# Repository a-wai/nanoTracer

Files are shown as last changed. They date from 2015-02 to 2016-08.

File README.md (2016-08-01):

# nanoTracer
nanoTracer is a basic curve tracer for vacuum tubes. It uses an Arduino for its brain and a simple analog circuit provides measurements command and amplification.

## Dependencies
In order to build this software, you need the following packages :

- GNU make
- avr-gcc
- avr-libc
- avr-binutils
- avrdude

These can be obtained by typing the following command on Debian or Ubuntu systems :

`sudo apt-get install avr-gcc avr-libc avr-binutils avrdude`

## Building nanoTracer
Simply `cd` into the `nanoTracer` directory and use the `make` command.

## Uploading nanoTracer to your device
nanoTracer is compatible with Arduino boards. Once the software has been built, simply type `make upload` to write the software to your device.

When using the AVR Dragon programmer, you need to modify a few variables in the Makefile :

- `PROGRAMMER	= dragon_isp`
- `PROG_PORT	= usb`

## Usage
The Arduino needs to be connected to a computer through USB. The use of a serial terminal, such as `minicom` or `Putty` is required, with a baudrate of 500kbps.

With minicom, use the command `minicom -D /dev/ttyACM0 -b 500000 -o -w`, and make sure to disable software and hardware flow control.

Once the Arduino is ready, it should ouput the string `Starting...`. You can then select the tube type you want to measure by typing its number in the serial terminal window :

- `1` for an ECC81
- `2` for an ECC82
- `3` for an ECC83
- `8` for an ECC88
- `9` for an ECC99

The measure is started by typing `#` in the serial terminal or pressing the hardware button connected to pin D2. The Arduino then outputs a list of measures of the form :

```
Vg = 20
57,1
76,1
92,2
108,5
...
```

Each `Vg = ` line indicates the grid voltage used for this measurement. It is expressed in tenths of volts, for instance, `Vg = 20` means the grid voltage is -2V.

The following lines are the measurements in CSV format, the first value being the anode voltage in V, and the second value being the anode current in tenths of milliamperes. Thus, the line `92,2` means the tube was drawing 0.2mA when the anode voltage was 92V (and the grid voltage -2V). You can then copy/paste these lines in your favorite spreadsheet to exploit the measurements (see the example LibreOffice file in the `spreadsheet/` directory).

## Harware
nanoTracer is a DIY project. You will find all the information needed to build your own tracer under the `kicad/` directory.

## License
Source code for the software is distributed under the GNU GPL v3 license. Please see the COPYING.software file or [the GNU website](http://www.gnu.org/licenses/#GPL) for details.

Hardware design files are distributed under the CERN Open Hardware Licence v1.2. Please see the COPYING.hardware file or [the Open Hardware Repository website](http://www.ohwr.org/licenses/cern-ohl/v1.2) for details.

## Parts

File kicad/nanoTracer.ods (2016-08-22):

Designator | Package | Qty | Value | RS Reference
 | 2.54mm Jumpers | 3 |  | 674-2397
P7 (optional) | Pin Header Straight 1x2 | 1 |  | 251-8086
SHIELD1,JP1,JP2,P6 | Pin Header Straight 1x40 | 1 |  | 156-049
D1,D3 | Rectifier Bridge WOG | 2 | B80C1500 | 700-5396
D2 | Rectifier Bridge WOG | 1 | B380C1500 | 629-6011
P3 | Bornier 3 | 1 |  | 897-0705
P1,P2,P4,P5 | Bornier 2 | 4 |  | 896-6696
C4,C5 | C_Rect_L18_W6_H12_P15 | 2 | 100n | 869-7469
C13,C2,C3,C10,C11,C14,C15 | C_Rect_L7_W2_P5 | 7 | 100n | 334-221
C1 | C_Radial_D10_L16_P5 | 1 | 1000µ | 862-3099
C6 | C_Radial_D7.5_L11.2_P2.5 | 1 | 220µ | 228-6919
C7 | C_Radial_D6.3_L11.2_P2.5 | 1 | 100µ | 228-6767
R12 | Resistor | 1 | 1R | 150-565
R16 | Resistor | 1 | 120R | 148-281
R5,R13 | Resistor | 2 | 1k | 148-506
R11 | Resistor | 1 | 2.2k | 148-584
R15 | Resistor | 1 | 2.4k | 148-590
R4 | Resistor | 1 | 5.1k | 148-253
R6,R7,R14 | Resistor | 3 | 10k | 148-736
R3 | Resistor | 1 | 15k | 148-770
R2 | Resistor | 1 | 82k | 148-950
R8,R9 | Resistor | 2 | 100k | 148-972
R10 | Resistor | 1 | 220k | 149-060
U1,U2,U3,U5 | DIP-8 Socket | 4 |  | 674-2479
U1 | DIP-8 | 1 | TL072 | 304-239
U2 | DIP-8 | 1 | TL071 | 304-245
U3 | DIP-8 | 1 | MCP4921-E/P | 738-6027
U4 | TO-220 | 1 | LM337T | 464-104
U5 | DIP-8 | 1 | MCP3202 | 403-115

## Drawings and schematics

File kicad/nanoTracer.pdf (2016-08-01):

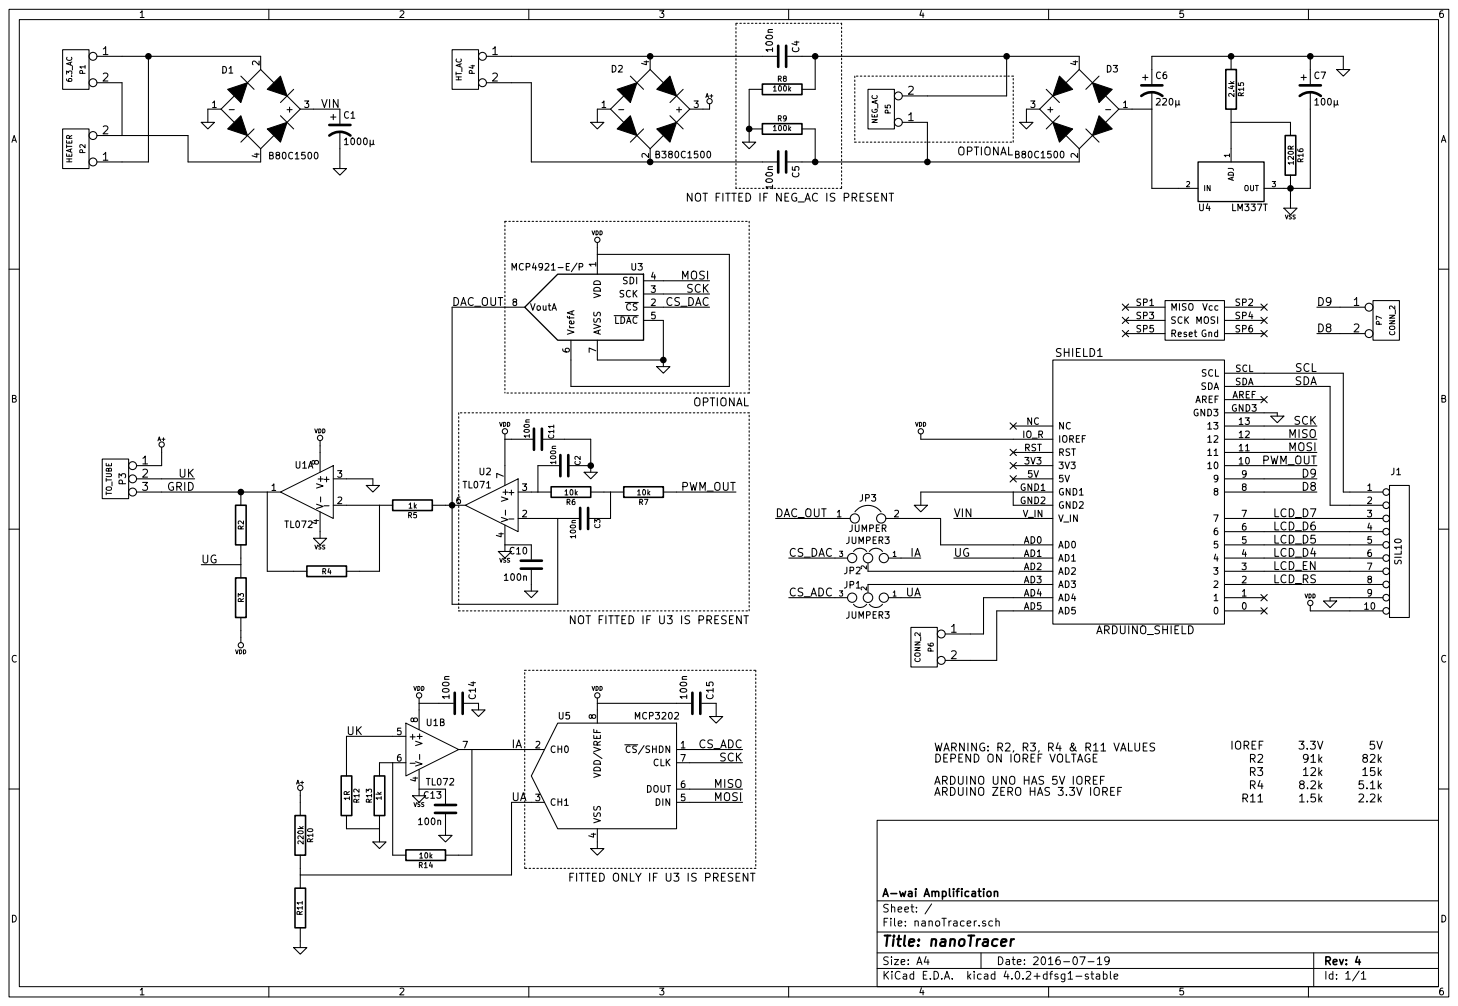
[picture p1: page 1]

100k NOT FITTED IF U3 IS PRESENT

NOT FITTED IF NEG_AC IS PRESENT

FITTED ONLY IF U3 IS PRESENT R2

DEPEND ON IOREF VOLTAGE
ARDUINO UNO HAS 5V IOREF

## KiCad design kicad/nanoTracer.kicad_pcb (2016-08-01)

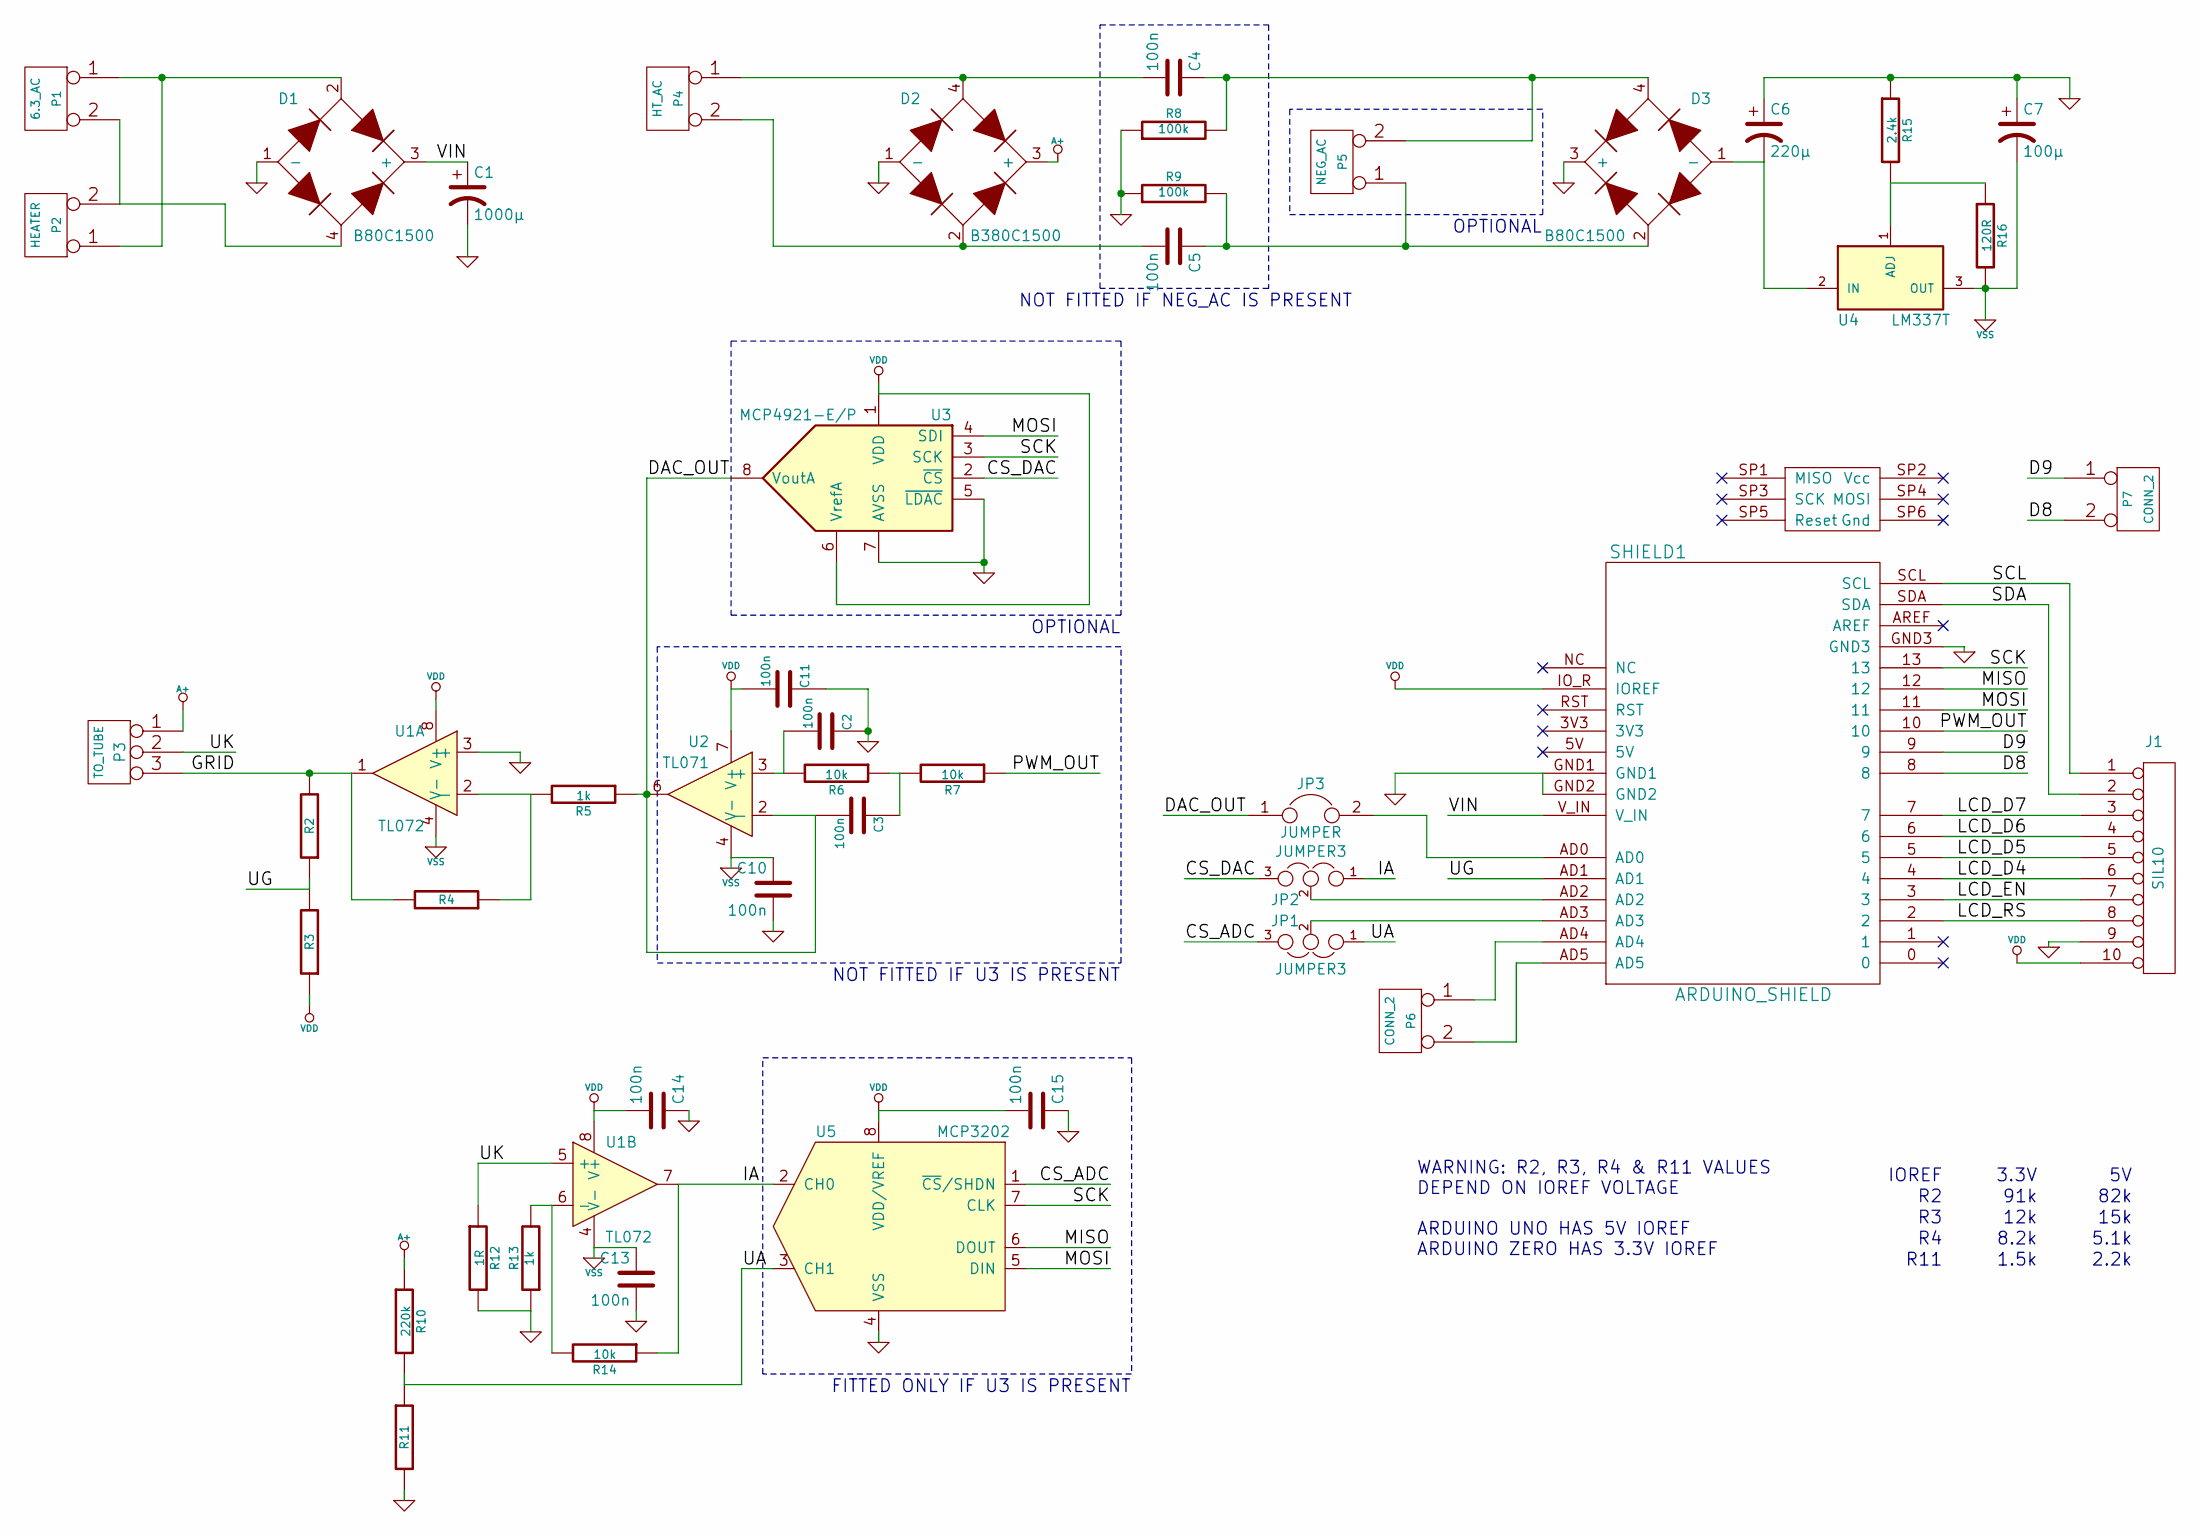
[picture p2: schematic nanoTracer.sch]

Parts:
C1: 1000µ; C_Radial_D10_L16_P5
C2, C3, C10, C11, C13, C14, C15: 100n; C_Rect_L7_W2_P5
C4, C5: 100n; C_Rect_L18_W6_H12_P15
C6: 220µ; C_Radial_D7.5_L11.2_P2.5
C7: 100µ; C_Radial_D6.3_L11.2_P2.5
D1, D3: B80C1500; bridge_wob
D2: B380C1500; bridge_wob
J1: SIL10; Pin_Header_Straight_1x10
JP1, JP2: JUMPER3; Pin_Header_Straight_1x03
JP3: JUMPER; SJ_OPEN
P1: 6.3_AC; bornier2
P2: HEATER; bornier2
P3: TO_TUBE; bornier3
P4: HT_AC; bornier2
P5: NEG_AC; bornier2
P6, P7: CONN_2; Pin_Header_Straight_1x02
R2: R2; Resistor_Horizontal_RM10mm
R3: R3; Resistor_Horizontal_RM10mm
R4: R4; Resistor_Horizontal_RM10mm
R5, R13: 1k; Resistor_Horizontal_RM10mm
R6, R7, R14: 10k; Resistor_Horizontal_RM10mm
R8, R9: 100k; Resistor_Horizontal_RM10mm
R10: 220k; Resistor_Horizontal_RM10mm
R11: R11; Resistor_Horizontal_RM10mm
R12: 1R; Resistor_Horizontal_RM10mm
R15: 2.4k; Resistor_Horizontal_RM10mm
R16: 120R; Resistor_Horizontal_RM10mm
SHIELD1: ARDUINO_SHIELD
U1: TL072; DIP-8_W7.62mm_LongPads
U2: TL071; DIP-8_W7.62mm_LongPads
U3: MCP4921-E/P; DIP-8_W7.62mm_LongPads
U4: LM337T; TO-220_Neutral123_Vertical
U5: MCP3202; DIP-8_W7.62mm_LongPads

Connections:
/CS_ADC: JP1.3, U5.1 (~CS~/SHDN)
/CS_DAC: JP2.3, U3.2 (~CS~)
/D8: P7.2, SHIELD1.8
/D9: P7.1, SHIELD1.9
/DAC_OUT: C3.2, JP3.1, R5.1, U2.2 (-), U2.6, U3.8 (VoutA)
/GRID: P3.3, R2.2, R4.2, U1.1
/IA: JP2.1, R14.1, U1.7, U5.2 (CH0)
/LCD_D4: J1.6, SHIELD1.4
/LCD_D5: J1.5, SHIELD1.5
/LCD_D6: J1.4, SHIELD1.6
/LCD_D7: J1.3, SHIELD1.7
/LCD_EN: J1.7, SHIELD1.3
/LCD_RS: J1.8, SHIELD1.2
/MISO: SHIELD1.12, U5.6 (DOUT)
/MOSI: SHIELD1.11, U3.4 (SDI), U5.5 (DIN)
/PWM_OUT: R7.1, SHIELD1.10
/SCK: SHIELD1.13, U3.3 (SCK), U5.7 (CLK)
/SCL: J1.1, SHIELD1.SCL
/SDA: J1.2, SHIELD1.SDA
/UA: JP1.1, R10.2, R11.1, U5.3 (CH1)
/UG: R2.1, R3.2, SHIELD1.AD1
/UK: P3.2, R12.1, U1.5 (+)
/VIN: C1.1, D1.3 (+), SHIELD1.V_IN
A+: D2.3 (+), P3.1, R10.1
GND: C1.2, C2.1, C6.1, C7.1, C10.2, C11.1, C13.2, C14.1, C15.1, D1.1 (-), D2.1 (-), D3.3 (+), J1.9, R8.1, R9.1, R11.2, R12.2, R13.1, R15.1, SHIELD1.GND1, SHIELD1.GND2, SHIELD1.GND3, U1.3 (+), U3.5 (~LDAC~), U3.7 (AVSS), U5.4 (VSS)
unnamed: C2.2, R6.2, U2.3 (+)
unnamed: C3.1, R6.1, R7.2
unnamed: C4.1, D3.4, P5.2 (PM), R8.2
unnamed: C4.2, D2.4, P4.1
unnamed: C5.1, D3.2, P5.1, R9.2
unnamed: C5.2, D2.2, P4.2 (PM)
unnamed: C6.2, D3.1 (-), U4.2 (IN)
unnamed: D1.2, P1.1, P2.1
unnamed: D1.4, P1.2 (PM), P2.2 (PM)
unnamed: JP1.2, SHIELD1.AD3
unnamed: JP2.2, SHIELD1.AD2
unnamed: JP3.2, SHIELD1.AD0
unnamed: P6.1, SHIELD1.AD4
unnamed: P6.2, SHIELD1.AD5
unnamed: R4.1, R5.2, U1.2 (-)
unnamed: R13.2, R14.2, U1.6 (-)
unnamed: R15.2, R16.1, U4.1 (ADJ)
VDD: C11.2, C14.2, C15.2, J1.10, R3.1, SHIELD1.IO_R (IOREF), U1.8 (V+), U2.7 (V+), U3.1 (VDD), U3.6 (VrefA), U5.8 (VDD/VREF)
VSS: C7.2, C10.1, C13.1, R16.2, U1.4 (V-), U2.4 (V-), U4.3 (OUT)

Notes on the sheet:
NOT FITTED IF U3 IS PRESENT
NOT FITTED IF NEG_AC IS PRESENT
FITTED ONLY IF U3 IS PRESENT
OPTIONAL
IOREF
R11
3.3V
82k
15k
5.1k
2.2k
1.5k
8.2k
12k
91k
WARNING: R2, R3, R4 & R11 VALUES DEPEND ON IOREF VOLTAGE ARDUINO UNO HAS 5V IOREF ARDUINO ZERO HAS 3.3V IOREF

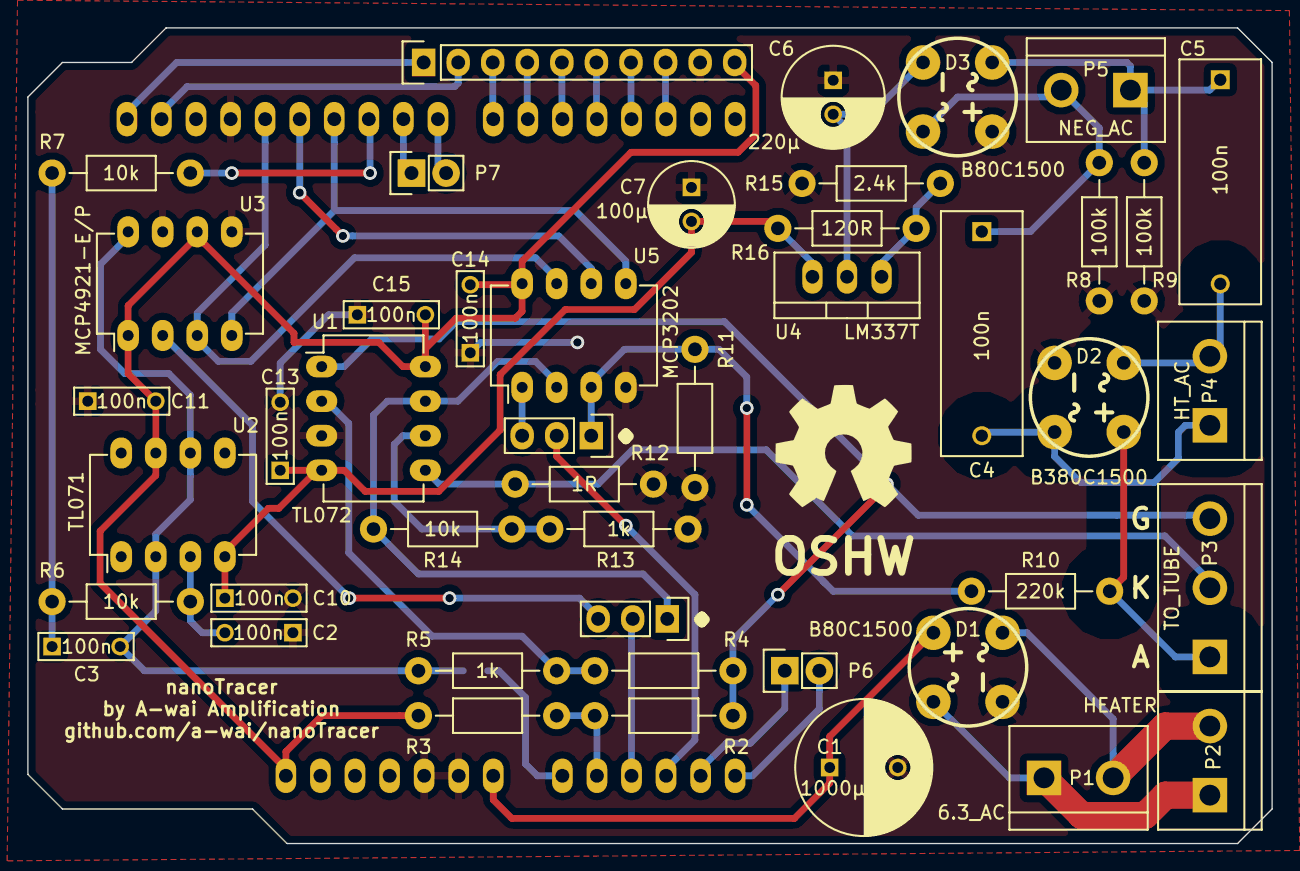
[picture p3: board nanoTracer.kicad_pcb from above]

Board: 2 copper layers, 91.4 x 59.9 mm, 48 parts (0 on the bottom side), 44 nets.

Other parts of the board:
LOGO_OSHW_silkscreen_10mm: val**; LOGO_OSHW_silkscreen_10mm

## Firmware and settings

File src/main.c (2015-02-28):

/*
 * Copyright (C) 2015 Arnaud Ferraris.
 *
 * This file is part of nanoTracer.
 *
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
 */

#include "main.h"
#include "tracer.h"

static program_mode_t mode = MODE_NONE;

static void mcuInit(void)
{
  // Enable sleep mode in idle mode
  SMCR = _BV(SE);

  // Disable ADC power reduction
  BITCLR(PRR, PRADC);
}

static void ioInit(void)
{
  // Configure pin D2 as input
  BITCLR(BTN_PORT, BTN_PIN);
  BITCLR(BTN_DDR, BTN_PIN);

  // Enable external interrupt on falling edge for pin D2
  EICRA = _BV(ISC00) | _BV(ISC01);
  EIMSK = _BV(INT0);
}

static void pwmInit(void)
{
  // Configure pin D6 as output
  BITSET(PORT_DIG1, PIN_D6);
  BITSET(DDR_DIG1, PIN_D6);

  // Configure TIMER0 for fast PWM
  TCCR0A = _BV(COM0A1) | _BV(WGM01) | _BV(WGM00);
  TCCR0B = _BV(CS00);
  TIMSK0 = 0;
  OCR0A = 200;
}

int main(void)
{
  char cmd;
  program_mode_t willDo = MODE_NONE;

  wdt_disable();

  cli();

  mcuInit();

  ioInit();
  pwmInit();
  serialInit(500000);
  adcInit(PIN_VOLTAGE);

  sei();

  serialDebug("Starting...\r\n");

  for (;;)
  {
    if (willDo)
    {
      mode = willDo;
      willDo = MODE_NONE;
    }
    else
    {
      asm volatile ("sleep\n\t");
    }

    switch (mode)
    {
      case MODE_START_ACQUISITION:
        tracerStartAcquisition();
        break;
      case MODE_CONVERSION_DONE:
        tracerProcessAdc();
        break;
      case MODE_SERIAL_RECEIVED:
        cmd = serialReceive();
        switch (cmd)
        {
          case '#':
            willDo = MODE_START_ACQUISITION;
            break;
          default:
            tracerSelectTube(cmd);
            break;
        }
        break;
      case MODE_SERIAL_SENT:
        serialWrite();
        break;
      default:
        break;
    }

    mode = MODE_NONE;
  }

  return 0;
}

ISR(INT0_vect)
{
  mode = MODE_START_ACQUISITION;
}

ISR(ADC_vect)
{
  mode = MODE_CONVERSION_DONE;
}

ISR(USART_RX_vect)
{
  mode = MODE_SERIAL_RECEIVED;
}

ISR(USART_TX_vect)
{
  mode = MODE_SERIAL_SENT;
}

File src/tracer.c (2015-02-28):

/*
 * Copyright (C) 2015 Arnaud Ferraris.
 *
 * This file is part of nanoTracer.
 *
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
 */

#include "drivers/adc.h"

#include "tracer.h"

#define   MAX_GRID_VOLTAGE  (10 * MAX_NEGATIVE_VOLTAGE)

uint16_t values[64];

static uint8_t  startAcquisition = 0;
static uint16_t oldValue         = 0;
static uint8_t  measureCount     = 0;
static uint8_t  currentStep      = 0;
static uint8_t  maxSteps         = 0;

static uint8_t  gridVoltages[MAX_STEPS];

void tracerStartAcquisition(void)
{
  if (maxSteps > 0)
  {
    adcSelectSource(PIN_VOLTAGE);
    startAcquisition = 1;
    oldValue = 0xFFFF;
    measureCount = 0;
    currentStep = 0;
    tracerSetGridVoltage(gridVoltages[currentStep]);
    adcStart();
  }
  else
  {
    serialSend("Tube type not defined, measurement aborted...\r\n");
  }
}

void tracerSelectTube(char tube)
{
  uint8_t maxVoltage, voltageStep, voltage, i = 0;
  char family = 0;
  char msg[100];

  switch (tube)
  {
    case '1': // ECC81
      voltageStep = 10;
      maxVoltage = 60;
      break;
    case '2': // ECC82
      voltageStep = 20;
      maxVoltage = 200;
      break;
    case '3': // ECC83
      voltageStep = 5;
      maxVoltage = 40;
      break;
    case '8': // ECC88
      voltageStep = 10;
      maxVoltage = 60;
      break;
    case '9': // ECC99
      voltageStep = 20;
      maxVoltage = 200;
      family = tube;
      break;
    default:
      voltageStep = 0;
      maxVoltage = 0;
  }

  if (!family)
  {
    family = '8';
  }

  if (maxVoltage > MAX_GRID_VOLTAGE)
  {
    maxVoltage = MAX_GRID_VOLTAGE;
  }

  for (voltage = maxVoltage; voltage > 0; voltage -= voltageStep)
  {
    gridVoltages[i] = voltage;
    i++;
  }

  if (i)
  {
    gridVoltages[i] = 0;

    sprintf(msg, "Selected tube type ECC%c%c - \r\nMeasuring for %d grid voltages from -%dV to 0V\r\n",
        family, tube, i + 1, gridVoltages[0] / 10);
    serialSend(msg);
  }

  maxSteps = i;
}

void tracerSetGridVoltage(uint8_t voltage)
{
  uint16_t tmp = (uint16_t) voltage;

  tmp *= 255;
  tmp /= 100;
  OCR0A = (uint8_t) tmp;
}

program_mode_t tracerProcessAdc(void)
{
  static uint8_t acquiring;
  uint16_t adcValue;
  program_mode_t ret = MODE_NONE;

  if (startAcquisition)
  {
    acquiring = 0;
    startAcquisition = 0;
  }

  adcValue = adcRead();
  if (oldValue == 0xFFFF)
  {
    oldValue = adcValue;
  }

  if (!acquiring)
  {
    if ((oldValue < 100) && (adcValue > oldValue))
    {
      acquiring = 1;
    }
    oldValue = adcValue;
  }
  else
  {
    values[measureCount] = adcValue;
    measureCount++;

    if (measureCount % 2)
    {
      adcSelectSource(PIN_VOLTAGE);
      if (oldValue > adcValue)
      {
        values[measureCount - 1] = oldValue;
        acquiring = 0;
        tracerNextStep();
      }
      oldValue = adcValue;
    }
    else
    {
      adcSelectSource(PIN_CURRENT);
    }
  }

  return ret;
}

void tracerNextStep(void)
{
  tracerProcessResults();

  if (currentStep < maxSteps)
  {
    currentStep++;
    tracerSetGridVoltage(gridVoltages[currentStep]);
  }
  else
  {
    tracerSetGridVoltage(MAX_GRID_VOLTAGE);
    tracerStopAcquisition();
  }

  oldValue = 0xFFFF;
  measureCount = 0;
}

void tracerStopAcquisition(void)
{
  adcSelectSource(PIN_VOLTAGE);
  adcStop();
}

void tracerProcessResults(void)
{
  char print[512];
  char tmp[10];
  uint32_t uAnode, uGrille;
//	uint16_t	intGrille, decGrille;

  sprintf(print, "Vg = %d\r\n", gridVoltages[currentStep]);

  measureCount = (measureCount / 2) * 2;
  values[measureCount] = values[measureCount - 2];

  for (int i = 2; i < measureCount; i += 2)
  {
    uAnode = values[i] + values[i + 2];
    uAnode *= 505;
    uAnode /= 2048;

#if 1
    uGrille = values[i + 1];
    uGrille *= 505;
    uGrille /= 1024;

    sprintf(tmp, "%lu:%lu\r\n", uAnode, uGrille);
#else
    uGrille = values[i + 1];
    uGrille *= 735;
    uGrille = 512000 - uGrille;

    intGrille = uGrille / 48128;
    decGrille = (uGrille % 48128) * 10 / 48128;

    sprintf(tmp, "%lu:-%u.%u\r\n", uAnode, intGrille, decGrille);
#endif
    strcat(print, tmp);
  }

  serialDebug(print);
}

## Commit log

2015-02-28 Add KiCAD files & LibreOffice example spreadsheet
    [nanoTracer.ods, nanoTracer.sch]
2015-02-28 Ignore KiCaD backup file
2015-02-28 Add KiCAD cache libraries
2016-07-19 Start modular Arduino shield project
    [nanoTracer.sch]
2016-07-19 Use SCL/SDA pins for buttons to ease routing
    [nanoTracer.sch]
2016-07-19 Complete footprints association
    [nanoTracer.sch]
2016-07-19 Update schematics PDF
    [nanoTracer.sch]
2016-07-19 Fix incorrect frame on schematics
    [nanoTracer.sch]
2016-07-19 [SCH] Move BTN_UP/BTN_DN as not connected on Arduino Zero
    [nanoTracer.sch]
2016-07-22 Switch to 10-pin header w/I2C for expansion port
    [nanoTracer.sch]
2016-07-22 Update PDF schematic
2016-07-24 First PCB version
    [nanoTracer.kicad_pcb, nanoTracer.sch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]
2016-07-24 Fix diode bridges footprints in PCB
    [nanoTracer.kicad_pcb, nanoTracer.sch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]
2016-07-24 Fix vias diameter & remove unused pin
    [nanoTracer-B.Cu.gbr, nanoTracer-B.Mask.gbr, nanoTracer-Edge.Cuts.gbr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]
2016-07-26 Optimize routing & silkscreen
    [nanoTracer-B.Cu.gbr, nanoTracer-B.Mask.gbr, nanoTracer-Edge.Cuts.gbr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]
2016-08-01 Added headers for unconnected Arduino pins
    [nanoTracer.kicad_pcb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]
2016-08-22 Add BOM
    [nanoTracer.ods]

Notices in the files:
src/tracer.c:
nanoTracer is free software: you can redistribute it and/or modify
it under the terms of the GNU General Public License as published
